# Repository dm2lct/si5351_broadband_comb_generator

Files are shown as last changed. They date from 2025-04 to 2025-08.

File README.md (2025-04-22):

# SI5351 broadband comb generator

# A tightrope walk between cost efficiency and RF-performance...

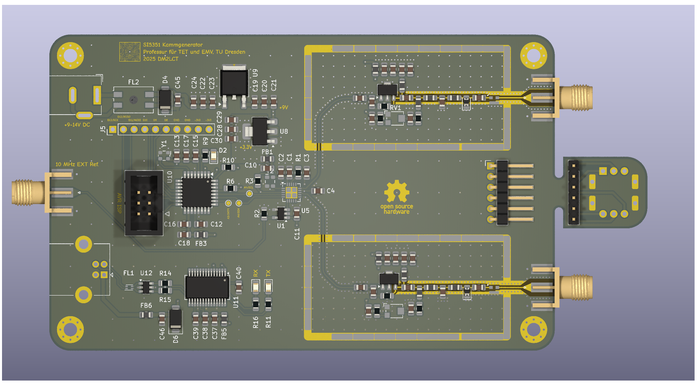
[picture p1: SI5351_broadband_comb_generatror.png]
3D-Picture of the comb-generator PCB in KiCAD


## Specs

The idea was, to build a programmable comb generator for RF and EMC measurements to validate some measurement gear like EMC receivers and to act as a reference source for some EMC measurement environments. 

To achieve a variable distance in the output spectrum, a programmable oscillator SI5351C is used. This SI5351C allows also to provide an external reference signal. Through this, it is possible to feed an external 10 MHz for example from a GPS-disciplined oscillator to achieve a precice and stable output frequency spectrum.

The goal is to reach an output spectrum with 100 MHz frequency marks up to 10 GHz

Let's see, if my design can do it...

## Disclaimer

You can use this design as it is open hardware but I assume there are some faults in my design. So please be careful. I'm always happy to get feedback on my designs. So feel free to write me a message if you think it could be helpful...

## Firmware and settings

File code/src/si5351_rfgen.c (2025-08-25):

/*****************************************************************/
/*             Comb generator with Si5153 and ATMega328PB        */
/*  ************************************************************ */
/*  Mikrocontroller:  ATMEL AVR ATmega328, 8 MHz                 */
/*                                                               */
/*  Compiler:         GCC (GNU AVR C-Compiler)                   */
/*  Author:           Luzia Christiane Tesar                     */
/*  Last Change:      2025-08-22                                */
/*****************************************************************/

// This is a minimal Firmware for the SI5351 Comb Generator
// Developed 2025 at the chair of elektromagnetic theory and 
// compatibility at TU Dresden
// it enables basic interpretion of some SCPI-Style commands and a manual control of the generator using a rotary switch
// The code snippet for the communication with the si5351 is a fork from DK7IH:
// https://dk7ih.de/a-simple-software-to-control-the-si5351a-generator-chip/

#define F_CPU 8000000UL
#include <inttypes.h>
#include <stdio.h>
#include <stdlib.h>
#include <math.h>
#include <string.h>

#include <avr/io.h>
#include <avr/interrupt.h>
#include <avr/sleep.h>
#include <avr/eeprom.h>
#include <util/delay.h>
#include <util/atomic.h>
#include "uart.h"

#define BAUDRATE 9600
#define TRUE 1
#define FALSE 0

#define CHAR_NEWLINE '\n'
#define CHAR_RETURN '\r'
#define RETURN_NEWLINE "\r\n"
#define CR "\r\n"
volatile unsigned char data_in[32];
unsigned char command_in[32];

volatile unsigned char data_count;
volatile unsigned char command_ready;
volatile unsigned char remote;

volatile char cmd[32], value[32], unit[32];
unsigned long t1, freq;

/////////////////////
//Defines for Si5351
/////////////////////
#define SI5351_ADDRESS 0xC0 // 0b11000000 for my module. Others may vary! The 0x60 did NOT work with my module!

//Set of Si5351A register addresses
#define CLK_ENABLE_CONTROL       3
#define PLLX_SRC		15
#define CLK0_CONTROL            16 
#define CLK1_CONTROL            17
#define CLK2_CONTROL            18
#define CLK3_CONTROL            19
#define CLK4_CONTROL            20
#define CLK5_CONTROL            21
#define CLK6_CONTROL            22
#define CLK7_CONTROL            23
#define SYNTH_PLL_A             26
#define SYNTH_PLL_B             34
#define SYNTH_MS_0              42
#define SYNTH_MS_1              50
#define SYNTH_MS_2              58
#define PLL_RESET              177
#define XTAL_LOAD_CAP          183

//The unavoidable functional stuff
int main(void);
void wait_ms(int);

//  TWI Declarations
void twi_init(void);
void twi_start(void);
void twi_stop(void);
void twi_write(uint8_t u8data);
uint8_t twi_get_status(void);

//  SI5351 Declarations
void si5351_write(int, int);
void si5351_start(void);
void si5351_set_freq(int, unsigned long);

/////////////////////
//
//   TWI-Functions
//
/////////////////////
void twi_init(void)
{
    //set SCL to 400kHz
    TWSR0 = 0x00;
    TWBR0 = 0x0C;
	
    //enable TWI
    TWCR0 = (1<<TWEN);
}

//Send start signal
void twi_start(void)
{
    TWCR0 = (1<<TWINT)|(1<<TWSTA)|(1<<TWEN);
    while ((TWCR0 & (1<<TWINT)) == 0);
}

//send stop signal
void twi_stop(void)
{
    TWCR0 = (1<<TWINT)|(1<<TWSTO)|(1<<TWEN);
}

void twi_write(uint8_t u8data)
{
    TWDR0 = u8data;
    TWCR0 = (1<<TWINT)|(1<<TWEN);
    while ((TWCR0 & (1<<TWINT)) == 0);
}

////////////////////////////////
//
// Si5351A commands
//
///////////////////////////////
void si5351_write(int reg_addr, int reg_value)
{
   twi_start();
   twi_write(SI5351_ADDRESS);
   twi_write(reg_addr);
   twi_write(reg_value);
   twi_stop();
} 

// Set PLLs (VCOs) to internal clock rate of 900 MHz 
// Equation fVCO = fXTAL * (a+b/c) (=> AN619 p. 3 
void si5351_start(void) 
{ 
  unsigned long a, b, c; 
  unsigned long p1, p2, p3; 
   
  // Init clock chip 
  si5351_write(XTAL_LOAD_CAP, 0xD2);      // Set crystal load capacitor to 10pF (default),  
                                          // for bits 5:0 see also AN619 p. 60 
  si5351_write(CLK_ENABLE_CONTROL, 0x7E); // Enable CLK0 and CLK7 
  si5351_write(CLK0_CONTROL, 0x0F);       // Set PLLA to CLK0, 8 mA output 
  si5351_write(CLK1_CONTROL, 0x80);       // CLK1 output OFF 
  si5351_write(CLK2_CONTROL, 0x80);       // CLK2 output OFF 
  si5351_write(CLK3_CONTROL, 0x80);       // CLK3 output OFF 
  si5351_write(CLK4_CONTROL, 0x80);       // CLK4 output OFF 
  si5351_write(CLK5_CONTROL, 0x80);       // CLK5 output OFF 
  si5351_write(CLK6_CONTROL, 0x80);       // CLK6 output OFF 
  si5351_write(CLK7_CONTROL, 0x80);       // CLK7 output OFF
  si5351_write(PLL_RESET, 0xA0);          // Reset PLLA and PLLB 
 
  // Set VCOs of PLLA and PLLB to 900 MHz 
  a = 36;           // Division factor 900/25 MHz 
  b = 0;            // Numerator, sets b/c=0 
  c = 1048575;      //Max. resolution, but irrelevant in this case (b=0) 
 
  //Formula for splitting up the numbers to register data, see AN619 
  p1 = 128 * a + (unsigned long) (128 * b / c) - 512; 
  p2 = 128 * b - c * (unsigned long) (128 * b / c); 
  p3  = c; 
 
  //Write data to registers PLLA and PLLB so that both VCOs are set to 900MHz intermal freq 
  si5351_write(SYNTH_PLL_A, 0xFF); 
  si5351_write(SYNTH_PLL_A + 1, 0xFF); 
  si5351_write(SYNTH_PLL_A + 2, (p1 & 0x00030000) >> 16); 
  si5351_write(SYNTH_PLL_A + 3, (p1 & 0x0000FF00) >> 8); 
  si5351_write(SYNTH_PLL_A + 4, (p1 & 0x000000FF)); 
  si5351_write(SYNTH_PLL_A + 5, 0xF0 | ((p2 & 0x000F0000) >> 16)); 
  si5351_write(SYNTH_PLL_A + 6, (p2 & 0x0000FF00) >> 8); 
  si5351_write(SYNTH_PLL_A + 7, (p2 & 0x000000FF)); 
 
  si5351_write(SYNTH_PLL_B, 0xFF); 
  si5351_write(SYNTH_PLL_B + 1, 0xFF); 
  si5351_write(SYNTH_PLL_B + 2, (p1 & 0x00030000) >> 16); 
  si5351_write(SYNTH_PLL_B + 3, (p1 & 0x0000FF00) >> 8); 
  si5351_write(SYNTH_PLL_B + 4, (p1 & 0x000000FF)); 
  si5351_write(SYNTH_PLL_B + 5, 0xF0 | ((p2 & 0x000F0000) >> 16)); 
  si5351_write(SYNTH_PLL_B + 6, (p2 & 0x0000FF00) >> 8); 
  si5351_write(SYNTH_PLL_B + 7, (p2 & 0x000000FF)); 
 
} 
 
void si5351_set_freq(int synth, unsigned long freq) 
{ 
   
  unsigned long  a, b, c = 1048575; 
  unsigned long f_xtal = 25000000; 
  double fdiv = (double) (f_xtal * 36) / freq; //division factor fvco/freq (will be integer part of a+b/c) 
  double rm; //remainder 
  unsigned long p1, p2, p3; 
   
  a = (unsigned long) fdiv; 
  rm = fdiv - a;  //(equiv. b/c) 
  b = rm * c; 
  p1  = 128 * a + (unsigned long) (128 * b / c) - 512; 
  p2 = 128 * b - c * (unsigned long) (128 * b / c); 
  p3 = c; 
   
  //Write data to multisynth registers of synth n 
  si5351_write(synth, 0xFF);      //1048757 MSB 
  si5351_write(synth + 1, 0xFF);  //1048757 LSB 
  si5351_write(synth + 2, (p1 & 0x00030000) >> 16); 
  si5351_write(synth + 3, (p1 & 0x0000FF00) >> 8); 
  si5351_write(synth + 4, (p1 & 0x000000FF)); 
  si5351_write(synth + 5, 0xF0 | ((p2 & 0x000F0000) >> 16)); 
  si5351_write(synth + 6, (p2 & 0x0000FF00) >> 8); 
  si5351_write(synth + 7, (p2 & 0x000000FF)); 
} 
/////////////////////////////////////////////
//              M  I  S  C  
/////////////////////////////////////////////
//Substitute defective _delay_ms() function in delay.h
void wait_ms(int ms)
{
    int t1, t2;
    int dtime = (int) 137 * 8;

    for(t1 = 0; t1 < ms; t1++)
    {
        for(t2 = 0; t2 < dtime; t2++)
        {
            asm volatile ("nop" ::);
        }
    }        
}

/////////////////////////////////////////////
//              U  A  R  T  
/////////////////////////////////////////////

void uart_init (void)
{
    //uint8_t sreg = SREG;
    uint16_t ubrr = (uint16_t) ((uint32_t) F_CPU/(16UL*BAUDRATE) - 1);

    UBRR0H = (uint8_t) (ubrr>>8);
    UBRR0L = (uint8_t) (ubrr);
    // Interrupts kurz deaktivieren 
    cli();
    // UART Receiver und Transmitter anschalten, Receive-Interrupt aktivieren 
    // Data mode 8N1, asynchron 
    UCSR0B = (1 << RXEN0) | (1 << TXEN0) | (1 << RXCIE0);
    UCSR0C = (0 << 4) | (0 << 3) | (3 << 1);
    // Flush Receive-Buffer (entfernen evtl. vorhandener ungültiger Werte) 
    do
    {
        // UDR auslesen (Wert wird nicht verwendet) 
        UDR0;
    }
    while (UCSR0A & (1 << RXC0));

    // Rücksetzen von Receive und Transmit Complete-Flags 
    UCSR0A = (1 << RXC0) | (1 << TXC0);

}


int uart_putc (const uint8_t c)
{
	    // Warten, bis UDR bereit ist für einen neuen Wert
    while (!(UCSR0A & (1 << UDRE0)))
        ;

    // UDR Schreiben startet die Übertragung
    UDR0 = c;

    return 1;
}

void uart_puts (const char *s)
{
    do
    {
        uart_putc (*s);
    }
    while (*s++);
}


void usart_ok()
{
    uart_puts("OK\r\n");
}

void copy_command ()
{
    // The USART might interrupt this - don't let that happen!
    ATOMIC_BLOCK(ATOMIC_FORCEON) {
        // Copy the contents of data_in into command_in
        memcpy(command_in, data_in, 32);

        // Now clear data_in, the USART can reuse it now
        memset(data_in, 0, 32);
    }
}

void split_command(char str[]){
	str[strlen(str)-1] = '\0';
	strcpy(cmd, strtok(str , " "));
    	strcpy(value, strtok(NULL, " "));
    	strcpy(unit , strtok(NULL, " "));
}

void process_command()
{
	if (strcmp(cmd, "*IDN?")==0){
		remote = TRUE;
		uart_puts("TUD TET_EMV Kammgenerator V1.0\n");
	}
	else if (strcmp(cmd, "*RST")==0){
		si5351_write(CLK_ENABLE_CONTROL, 0xFF);  
		remote = FALSE;
	}
	else if (strcmp(cmd, "FREQ?")==0){                	
		remote = TRUE;
  		char f[32];
  		uart_puts(ltoa(freq,f,10));
		uart_puts(" Hz\n");
        }
	else if (strcmp(cmd, "FREQ")==0){
		remote = TRUE;
  		if (strcmp(unit, "Hz")==0){
			freq=atol(value);	
		}
		if (strcmp(unit, "kHz")==0){
			freq=atol(value)*1000;	
		}
		if (strcmp(unit, "MHz")==0){
			freq=atol(value)*1000000;	
		}
		if (freq >= 1000000 && freq <= 150000000){
			si5351_set_freq(SYNTH_MS_0, freq);
		}
		else {
			uart_puts("-100\n");
		}
	}
	else if (strcmp(cmd, "OUTP")==0){ 
		remote = TRUE;
		if (strcmp(value, "OFF")==0){
			si5351_write(CLK_ENABLE_CONTROL, 0xFF);  
		}
		else if (strcmp(value, "ON")==0){
			si5351_write(CLK_ENABLE_CONTROL, 0x7E); 
		}
		else {
			uart_puts("-100\n");
		}

	}
	else {
		uart_puts("-100\n");
	}


        
}

int main(void)
{
	int SwitchPos=0;
	int lastSwitchPos;	
	DDRD |= (1<< DDD2);
	DDRD  &= ~(1<<PD3)|~(1<<PD4)|~(1<<PD5)|~(1<<PD6)|~(1<<PD7);
	uart_init();
	sei();
	PORTC = 0x30;//I²C-Bus lines: PC4=SDA, PC5=SCL 
				
	twi_init();
	wait_ms(100);
	si5351_start();
	wait_ms(100);
    while (1)
    {
	if (command_ready == TRUE) {
		copy_command();
		split_command(command_in);
		process_command();
        	command_ready = FALSE;
        }
	PORTD |= (1 << PD2);  //PB0 im PORTB setzen
        wait_ms(100);
	if(PIND & (1 << PD3)) {
		//OFF/LOKAL
		SwitchPos=0;
	}
	if(PIND & (1 << PD4)) {
		//100k
		SwitchPos=1;
	}
	if(PIND & (1 << PD5)) {
		//1M
		SwitchPos=2;
	}
	if(PIND & (1 << PD6)) {
		//10M
		SwitchPos=3;
	}
	if(PIND & (1 << PD7)) {
		//100M
		SwitchPos=4;
	}
	
	wait_ms(100);
	PORTD &= ~(1 << PD2); //PD2 im PORTD löschen
	
	if(SwitchPos!=lastSwitchPos){
		switch(SwitchPos){
			case 0:
				remote=FALSE;
				si5351_write(CLK_ENABLE_CONTROL, 0xFF);  // Output off
			break;

			case 1:
				freq=1000000;
			break;

			case 2:
				freq=10000000;
			break;

			case 3:
				freq=50000000;
			break;

			case 4:
				freq=100000000;
			break;

		}	
		if(remote==FALSE && SwitchPos!=0){
			si5351_write(CLK_ENABLE_CONTROL, 0x7E); 
			si5351_set_freq(SYNTH_MS_0, freq);
		}
		lastSwitchPos=SwitchPos;
	}
    }

    return 0;
}

ISR(USART0_RX_vect)
{
	// Get data from the USART in register
    	data_in[data_count] = UDR0;

	// End of line!
    	if (data_in[data_count] == '\n') {
        	command_ready = TRUE;
		// Reset to 0, ready to go again
        	data_count = 0;
	} else {
        	data_count++;
    }
}

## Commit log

2024-12-06 initial commit... not much to expect
    [SI5351_broadband_comb_generatror.kicad_pcb, SI5351_broadband_comb_generatror.kicad_sch]
2024-12-09 working on the schematic...
    [SI5351_broadband_comb_generatror.kicad_sch, comb_generator.kicad_sch, controller.kicad_sch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]
2025-03-25 weiter layoutet...
    [SI5351_broadband_comb_generatror.kicad_pcb, SI5351_broadband_comb_generatror.kicad_sch, comb_generator.kicad_sch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]
2025-03-25 weiter layoutet
    [SI5351_broadband_comb_generatror.kicad_pcb]
2025-04-11 es wird langsam...
    [SI5351_broadband_comb_generatror.kicad_pcb, SI5351_broadband_comb_generatror.kicad_sch, comb_generator.kicad_sch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]
2025-04-14 es wird fast fertig...
    [SI5351_broadband_comb_generatror.kicad_pcb]
2025-04-15 noch ein paar Kleinigkeiten
    [SI5351_broadband_comb_generatror.kicad_pcb, controller.kicad_sch]
2025-04-15 BOM angefangen und im Layout vom Hundertsten ins Tausendste gekommen...
    [SI5351_broadband_comb_generatror.kicad_pcb, SI5351_broadband_comb_generatror.kicad_sch, comb_generator.kicad_sch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]
2025-04-16 es wird nicht besser... Beschriftungen und co. BOM angefangen...
    [SI5351_broadband_comb_generatror.kicad_pcb, SI5351_broadband_comb_generatror.kicad_sch, controller.kicad_sch]
2025-04-17 Maybe ready for production...
    [SI5351_broadband_comb_generatror.kicad_pcb, power_supply.kicad_sch]
2025-04-17 Maybe now... ready for production...
    [SI5351_broadband_comb_generatror.kicad_pcb, SI5351_broadband_comb_generatror.kicad_sch]
2025-04-22 BOM, README...
    [SI5351_broadband_comb_generatror.kicad_pcb, power_supply.kicad_sch]
2025-05-05 got samples von Minicircuits, change attenuator to GAT-x
    [SI5351_broadband_comb_generatror.kicad_pcb, comb_generator.kicad_sch]
2025-08-22 aktualisiert, Frequenz setzen, ID abfragen, ein und ausschalten geht jetzt
2025-08-25 Der Klassiker: RX und TX Leitungen vertauscht. Jetzt im Dutzend billiger. Korrigiert...
    [SI5351_broadband_comb_generatror.kicad_pcb, controller.kicad_sch]
